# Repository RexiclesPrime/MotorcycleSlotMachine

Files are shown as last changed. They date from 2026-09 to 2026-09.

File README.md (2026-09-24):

# Motorcycle Slot Machine

On power-on, an ESP32 picks today's bike on a three-reel e-ink slot.

The glass on the bench is black, white, and red. That panel lands on the result. A black-and-white panel spins the reels, then settles. The switch is `PANEL_COLORS` in `firmware/motorcycle_slot/config.h`: `3` or `2`.

| Code | Bike |
|---|---|
| **R6** | 2020 Yamaha R6 |
| **R12** | BMW R12 |
| **TT** | Triumph Thruxton R |
| **HS** | Honda Shadow (red bodywork) |
| **JP** | Jackpot — *Buy another motorcycle.* (red bow) |

Bikes are equally likely. Jackpot is about 1% (`2/198`). Reels draw 128×96 side-view sprites. After the result the ESP32 sleeps; tap a button on **GPIO 4** (to GND) to roll again. Wall case: `hardware/enclosure/`. Sources live in `assets/pixel/`; rebuild with `python tools/png_to_bitmap.py`.

## Hardware

- WeAct 4.2" e-paper, 400×300
  - 3-color, black/white/red (GDEY042Z98) — `PANEL_COLORS 3`
  - 2-color, black/white (GDEY042T81) — `PANEL_COLORS 2`
- ESP32 e-Paper Driver Board (USB 5V, 24-pin FPC)

## Load it onto a board

Step-by-step for a first-time Arduino user (plug in the screen, install the IDE, upload): **[HOW-TO-LOAD.md](HOW-TO-LOAD.md)**.

## License

[MIT](LICENSE) for the firmware, the case, and the project docs. Photographs in `assets/pixel/src/` are reference art for the sprites and are not covered by that license.

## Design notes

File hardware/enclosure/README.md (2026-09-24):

# Garage wall enclosure

Two-part PETG case: 4.2" e-paper on the front, ESP32 driver board + 18650 + charger behind, 16 mm **SPIN** button under the screen, keyholes to hang it.

Open `slot_wall_case.scad` in [OpenSCAD](https://openscad.org/). Set `part = "front";` then **F6 → Export STL**. Repeat with `part = "back";`.

Print **PETG** (a summer garage will warp PLA). 0.2 mm layers, 4 perimeters, 25 % infill, no supports if the USB cutouts print with bridging.

Outside is about **100 × 120 × 40 mm**. Measure your glass before the first print; the pocket is 91.5 × 77.5 mm for the usual 91 × 77 × 1.2 mm 4.2" panel.

## Spin button

Use a **16 mm stainless anti-vandal momentary (1NO)** panel switch. Garage dust and gloves, no arcade-button grit trap. Search: `16mm anti-vandal momentary 1NO stainless`. About $6. Panel thickness here is 2.6 mm (the switch’s spec range is usually 1–10 mm).

Skip the LED unless you want it — the ESP32 is asleep most of the time, so a lit button is extra drain.

Wire:

- One switch pin → **GND**
- Other switch pin → **IO4** on the ESP32 driver board (RTC pin, firmware `PIN_SPIN_BUTTON 4`)

Do **not** use BOOT (GPIO0). That is for flashing.

## Battery

Waveshare’s **5V** pin is specified **3.6–5.5 V**, so a single Li-ion cell can feed it directly.

| Part | Why |
|---|-----|
| **Protected 18650** (Panasonic NCR18650B or similar, with the PCB cap) | Garage-safe, ~2500–3400 mAh. Deep sleep + e-ink is months, not hours. |
| **TP4056 Type-C charger with protection** (DW01 / FS8205) | Charge through a hole in the bottom. Do not buy the tiny unprotected-only boards. |

Wiring:

```
USB-C  →  TP4056  B+ / B-  →  18650
                 OUT+  →  ESP32  5V pin
                 OUT-  →  ESP32  GND
```

If your TP4056 has no separate OUT pads, B+ / B- *are* the load — that is still 3.7–4.2 V into the 5V pin, which the board allows.

Leave the ESP32’s own USB for firmware, accessed through the side window or by popping the back.

## Assembly

1. Press four **M3 heat-set inserts** into the back bosses.
2. Stick a 1 mm EVA / craft-foam ring on the back’s glass rib (only the frame, not the picture area).
3. Drop the glass into the front pocket. FPC folds down into the bay — do not crease it sharply.
4. Seat the ESP32 (USB toward the side window), 18650 in the trough, TP4056 USB-C in the bottom cutout. Hot-glue the charger if it rattles.
5. Screw the back on with **M3×12**. Do not pinch the glass; the foam should just kiss the border.
6. Hang on two #8 pan-head screws, 60 mm apart, 14 mm down from the top.

Power on: 3-color glass takes 15–20 s to land on **TODAY'S RIDE**. 2-color glass spins the reels, then shows the same line. Tap **SPIN** to wake and roll again. The glass switch is `PANEL_COLORS` in `firmware/motorcycle_slot/config.h`.

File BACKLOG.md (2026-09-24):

# Punch list

Reviewed `main` at `788aa67` on 2026-09-24: firmware, art tool, odds check, and the wall case. Boot is in good shape. Power-on draws the result with a full refresh, then deep sleep. The old "spins forever" hang is capped.

The BMW R12 reel uses the studio photo from `R12.webp`, mirrored to face right with the other bikes. Reel art is `assets/pixel/src/r9.sprite.png` (128×96). The untouched photo is `assets/pixel/src/r12.webp`. Rebuild with `python tools/png_to_bitmap.py`.

## Decided

- The bench glass is black/white/red. `PANEL_COLORS` is `3`, and that build lands on the result. Set it to `2` for the black-and-white panels. The reels animate only on 2-color glass.
- The button may reroll. "TODAY'S RIDE" is the label, not a once-a-day lock.
- On a 2-color spin, a reel may flash the jackpot. That fake-out stays.
- License is MIT (`LICENSE`). Photographs in `assets/pixel/src/` are not part of that grant.

## P0 — overlapping reels, or a case that will not screw together

1. **Reel frames overlap, and the sprite is wider than its window.** On a 400×300 panel, `layOut()` in `motorcycle_slot.ino` makes each window 125×198 with a 6px gap. The frame is drawn 6px outside the window, so neighboring frames sit on the same pixels. `paintBadge()` then centers the 128px-wide bitmap in that 125px window, so 1–2px of every bike lands on the frame. Widen the gap, or shrink the art to the window.

2. **The wall case has no plastic around the screws.** In `hardware/enclosure/slot_wall_case.scad`, the M3 heat-set holes are 7mm deep, cut through a 2.6mm back wall, with no boss. An insert there has nothing to grip. Add corner bosses at least as deep as the insert before the first print.

## P1 — names, the spin button, and the art tool

3. **R6 and R12 are still called R7 and R9 in the code.** The glass labels are R6 and R12. The enum, the weight macros, the bitmap symbols, and the source files are still `R7` / `R9`. `tools/odds_check.py` prints `R9` for the BMW. One set of names, used everywhere.

4. **Holding the spin button can roll a second time.** Production arms `esp_sleep_enable_ext0_wakeup` on GPIO4, level low, then sleeps. Ext0 wakes if the pin is already low, so a press that outlasts the refresh starts another spin. Test mode already ignores a stuck pin. Production should wait until GPIO4 is high, then sleep. Confirm on the board.

5. **`SPRITE_INVERT` flips only the black plane.** In `paintBadge()`, the red bitmap is always drawn with `drawBitmap`. On a 3-color panel, inverting the bikes leaves the Shadow's paint and the jackpot bow alone.

6. **The art tool flattens a dark bike.** `tools/png_to_bitmap.py` marks any pixel darker than 200 as ink, then nearest-neighbor scales. A black motorcycle becomes a blob, and a gray floor shadow becomes a puddle. That is why the R12 is an authored `r9.sprite.png` instead of a straight threshold of the photo. Downscale first, and drop the near-white background, before the next photo.

## P2 — housekeeping

7. **The test splash still says "sprites on".** `bootSplash()` is leftover debug copy. Production never shows it. A real title, or no splash.

8. **The odds table is copied in two places.** Weights live in `config.h` and again in `odds_check.py`, which is how the checker ended up saying R9. One table.

9. **GPIO12 is claimed as MISO.** The e-paper board does not need a MISO line, and GPIO12 is an ESP32 strapping pin (flash voltage). Not claiming it avoids a boot failure if the ribbon floats that pin.

10. **Charger wiring in the enclosure notes.** `hardware/enclosure/README.md` says a TP4056 with no OUT pads can feed the ESP32 from B+ / B-. That is fine until the board is charging and running at the same time. Call for a load-sharing charger if this lives on USB-C in the garage.

11. **No check that the art and the odds still match.** A small script run (odds check, plus a diff of `bitmaps.h` after `png_to_bitmap.py`) would catch the next drift. Nothing in the repo runs either today.

## Leave alone

- `esp_random() % 198` is a hair off a perfect 2/198 jackpot. Nobody will see it.
- The 4-page cap in the draw loops. With a full-height buffer the draw is one page. That cap is what stopped the boot hang.

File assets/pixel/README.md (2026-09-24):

# Pixel art

Side-view 1-bit sprites for the three reels.

| File | Bike |
|---|---|
| `src/r7.jpg` | 2020 Yamaha R6 |
| `src/r9.jpg` | BMW R12 photo, mirrored so it faces right like the other reels |
| `src/r9.sprite.png` | BMW R12 reel art, already 128×96. The tool uses this as-is |
| `src/r12.webp` | BMW R12 studio photo, original (faces left) |
| `src/tt.jpg` | Triumph Thruxton R (cafe fairing) |
| `src/hs.jpg` | Honda Shadow (red body) |
| `src/jp.jpg` | Jackpot (gift-wrapped extra bike) |

Filenames `r7` and `r9` are older names. On the glass those reels are **R6** and **R12**.

`python tools/png_to_bitmap.py` writes 128×96 `1bit/*.png` and `firmware/motorcycle_slot/bitmaps.h`. A `src/<name>.sprite.png` at exactly 128×96 is copied through. Anything else is thresholded from the photo.

The MIT license does not cover these photographs. They are references for the reel sprites.

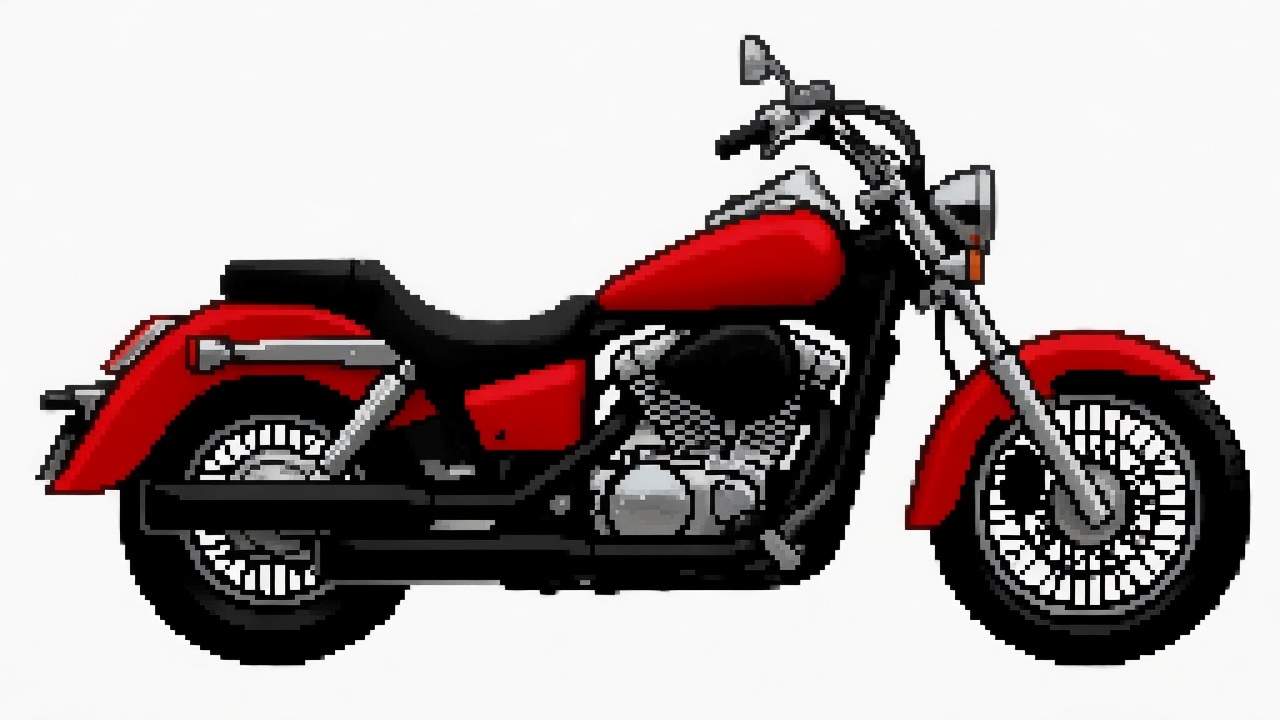
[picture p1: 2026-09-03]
assets/pixel/src/hs.jpg

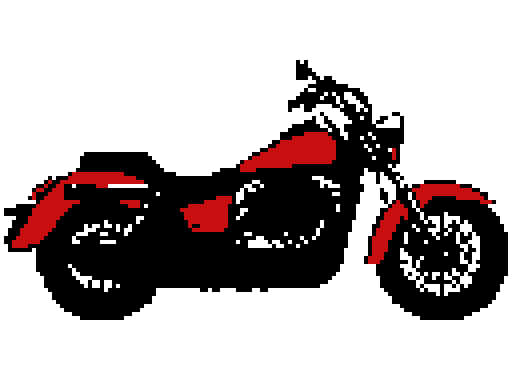
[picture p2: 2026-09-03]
assets/pixel/1bit/hs_x4.png

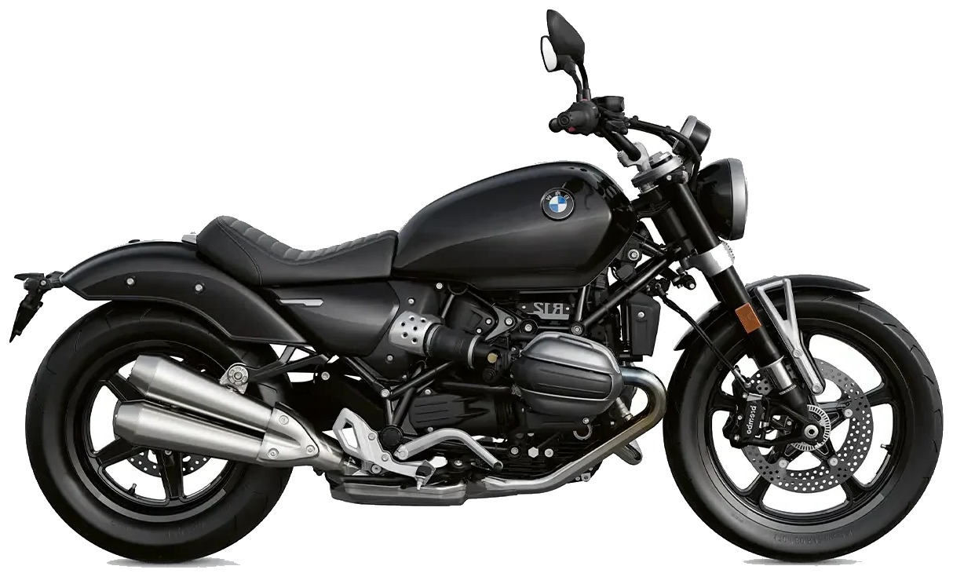
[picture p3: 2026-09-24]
assets/pixel/src/r9.jpg

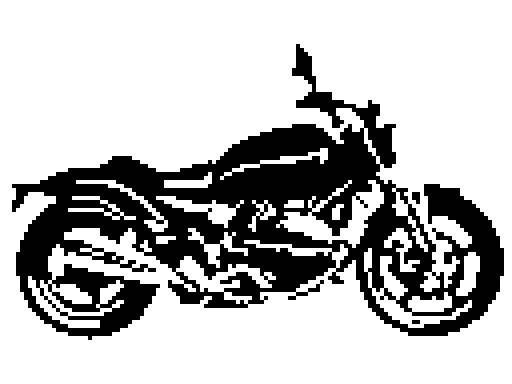
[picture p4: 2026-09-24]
assets/pixel/1bit/r9_x4.png

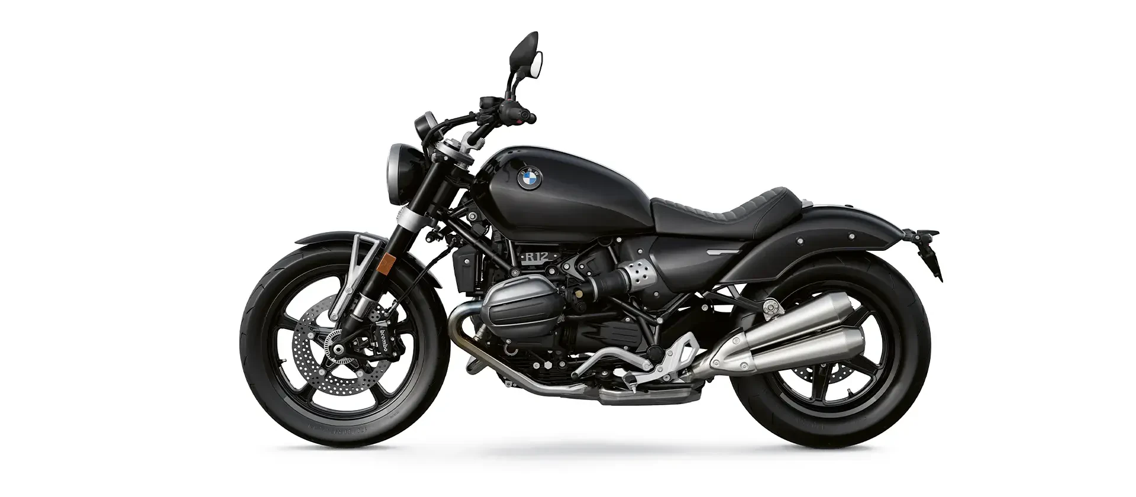
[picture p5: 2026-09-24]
assets/pixel/src/r12.webp

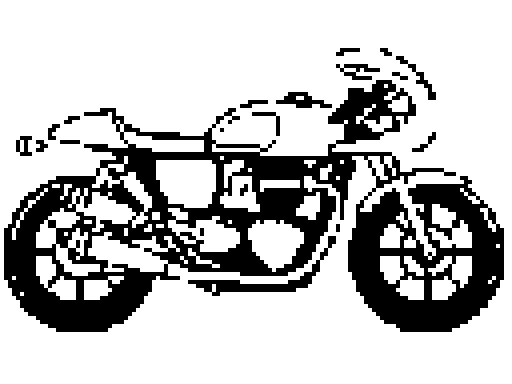
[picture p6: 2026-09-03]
assets/pixel/1bit/tt_x4.png

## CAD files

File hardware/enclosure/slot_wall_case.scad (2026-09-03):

// Motorcycle Slot Machine — garage wall case
// Units: millimetres
// OpenSCAD: set part = "front" or "back", press F6, File → Export → STL
// Print PETG (garage heat), 0.2 mm layers, 4 perimeters, 25% infill.

part = "preview"; // "front", "back", "preview"

$fn = 48;
clear = 0.35;

// --- 4.2" glass (WeAct / Good Display 400x300) ---
glass_w = 91.0;
glass_h = 77.0;
glass_t = 1.4;
aa_w = 84.8;
aa_h = 63.6;

// --- Waveshare ESP32 e-Paper Driver Board ---
esp_l = 48.5;
esp_w = 29.8;
esp_t = 8.5;

// --- 18650 + typical dual-slot holder / single keystone ---
cell_d = 19.2;
cell_l = 69.0;

// --- TP4056 Type-C charger (with protection) ---
chg_l = 27.0;
chg_w = 18.0;
chg_t = 6.0;

// --- 16 mm anti-vandal momentary ---
btn_hole = 16.2;
btn_boss_t = 2.6; // panel thickness at the button

wall = 2.6;
lip = 1.6;          // front window lip over the glass
bezel = 3.2;        // glass overlap around the active area
gap_g = 0.5;        // glass pocket clearance

inner_w = glass_w + 2 * gap_g;
inner_h = glass_h + 2 * gap_g;
win_w = aa_w - 1.2;
win_h = aa_h - 1.2;

btn_zone = 28;
case_w = inner_w + 2 * wall + 4;
case_h = inner_h + btn_zone + 2 * wall + 6;
case_d = wall + glass_t + 2.0 + esp_t + cell_d + wall; // ~40

front_t = wall + lip + glass_t + 1.2;
back_t = case_d - front_t + 1.2; // overlap seam

screw_r = 1.6;      // M3 clearance
insert_r = 2.05;    // M3 heat-set insert
boss_r = 4.2;

module rrect(s, r) {
  hull() {
    for (x = [r, s[0] - r], y = [r, s[1] - r])
      translate([x, y]) circle(r = r);
  }
}

module rbox(s, r) {
  linear_extrude(s[2]) rrect([s[0], s[1]], r);
}

module screw_xy() {
  m = wall + 3.5;
  for (x = [m, case_w - m], y = [m, case_h - m])
    translate([x, y]) children();
}

module keyhole() {
  // #8 / 4 mm screw, hang and drop
  hull() {
    circle(d = 8.5);
    translate([0, -7]) circle(d = 4.4);
  }
}

module front() {
  gx = (case_w - inner_w) / 2;
  gy = case_h - wall - 4 - inner_h;
  wx = gx + (inner_w - win_w) / 2;
  wy = gy + (inner_h - win_h) / 2;

  difference() {
    union() {
      rbox([case_w, case_h, front_t], 4);
      translate([wall - 0.8, wall - 0.8, front_t])
        rbox([case_w - 2 * wall + 1.6, case_h - 2 * wall + 1.6, 1.4], 3);
    }

    translate([wx, wy, -0.1])
      cube([win_w, win_h, front_t + 3]);

    translate([gx, gy, lip])
      cube([inner_w, inner_h, front_t]);

    // FPC folds down from the bottom edge of the glass
    translate([case_w / 2 - 9, gy - 3, lip + 0.3])
      cube([18, 6, front_t]);

    translate([case_w / 2, wall + 7 + btn_hole / 2, -0.1])
      cylinder(d = btn_hole, h = front_t + 4);

    screw_xy()
      translate([0, 0, -0.1]) cylinder(r = screw_r, h = front_t + 4);
  }

  translate([case_w / 2, wall + 7 + btn_hole + 5.2, front_t - 0.45])
    linear_extrude(0.55)
      text("SPIN", size = 4, halign = "center", valign = "center");
}

module back() {
  difference() {
    rbox([case_w, case_h, back_t], 4);

    // main cavity
    translate([wall, wall, wall])
      rbox([case_w - 2 * wall, case_h - 2 * wall, back_t], 3);

    // seam rebate for the front lip
    translate([wall - 1.0, wall - 1.0, back_t - 1.6])
      rbox([case_w - 2 * wall + 2.0, case_h - 2 * wall + 2.0, 2.2], 3);

    // M3 heat-set inserts
    screw_xy()
      translate([0, 0, -0.1]) cylinder(r = insert_r, h = 7);

    // USB-C charge (TP4056) on the bottom
    translate([case_w / 2 - 5, -0.1, wall + 4])
      cube([10, wall + 2, 6]);

    // ESP32 USB (programming) on the right side, case open not required if you
    // leave a 12 x 8 window — still easier to pop the back. Side window:
    translate([case_w - wall - 0.1, wall + 10, wall + 3])
      cube([wall + 1, 12, 8]);

    // keyholes (hang on two #8 pan heads)
    translate([case_w / 2 - 30, case_h - 14, -0.1])
      linear_extrude(wall + 0.3) keyhole();
    translate([case_w / 2 + 30, case_h - 14, -0.1])
      linear_extrude(wall + 0.3) keyhole();
  }

  // ESP32 standoffs (board sits USB toward the side window)
  translate([wall + 8, wall + 8, wall])
    for (x = [3, esp_l - 3], y = [3, esp_w - 3])
      translate([x, y, 0]) {
        difference() {
          cylinder(r = 3.2, h = 4);
          translate([0, 0, 1.2]) cylinder(r = 0.9, h = 4); // M2 self-tap
        }
      }

  // 18650 trough
  translate([wall + 8, wall + 8 + esp_w + 8, wall])
    difference() {
      cube([cell_l + 4, cell_d + 4, cell_d * 0.55]);
      translate([2, 2, 2]) cube([cell_l, cell_d, cell_d]);
    }

  // foam rib that presses the glass perimeter (not the active area)
  translate([(case_w - (inner_w - 6)) / 2,
             case_h - wall - 3 - inner_h + 3,
             back_t - 3.2])
    difference() {
      cube([inner_w - 6, inner_h - 6, 1.8]);
      translate([4, 4, -0.1])
        cube([inner_w - 14, inner_h - 14, 3]);
    }
}

if (part == "front") front();
else if (part == "back") back();
else {
  front();
  translate([case_w + 12, 0, 0]) back();
}

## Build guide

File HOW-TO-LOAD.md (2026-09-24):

# How to load this onto the hardware

You need:

- A **WeAct 4.2" e-paper** module (the glass + short ribbon cable)
- An **ESP32 e-Paper Driver Board** (the small USB board with a ribbon-cable socket)
- A USB cable that actually carries data (not charge-only)
- A computer with [Arduino IDE](https://www.arduino.cc/en/software) (version 2 is fine)

No extra jumper wires. The screen plugs into the driver board; the driver board plugs into the computer.

## 1. Connect the screen to the driver board

E-paper glass is fragile. Hold it by the edges. Do not press the face.

1. On the driver board, find the **24-pin FPC socket** (the thin slot with a plastic latch).
2. Gently lift the latch.
3. Slide the screen’s ribbon in **straight and fully**. Gold contacts go toward the contacts in the socket. If it fights you, you have it upside down — flip the ribbon, don’t force it.
4. Press the latch back down so the cable is locked.
5. Set the small **display / resistor switch** to **A** (often labeled **3R**). Leave the SPI switch on **4-line** if the board has one.

Then plug the driver board into the computer with USB. A power LED should light. If Windows pops up “USB device,” that is normal.

## 2. Install Arduino IDE and the ESP32 board package

1. Install Arduino IDE and open it.
2. **File → Preferences**. In *Additional boards manager URLs* paste:

   `https://espressif.github.io/arduino-esp32/package_esp32_index.json`

   Click OK.
3. **Tools → Board → Boards Manager…**
4. Search **esp32**. Install **esp32** by **Espressif Systems**. Close the manager.

## 3. Install the three libraries

This step is required. Installing only GxEPD2 is not enough — the fonts live in Adafruit GFX.

**Sketch → Include Library → Manage Libraries…** Search each name below, click **Install**, and accept **Install all** if it asks for dependencies.

| Search for | Author to pick |
|---|---|
| `GxEPD2` | Jean-Marc Zingg |
| `Adafruit GFX Library` | Adafruit |
| `Adafruit BusIO` | Adafruit |

To confirm GFX is actually there: **Sketch → Include Library** should list **Adafruit GFX Library**. If it does not, install it again (close and reopen the Library Manager if the list looks stale).

## 4. Open this project and pick the board

1. Get a **fresh** copy: GitHub **Code → Download ZIP**, unzip it, and throw away any older `MotorcycleSlotMachine-main` folder. Do not copy one new file into an old sketch folder — `bitmaps.h` has to sit next to the `.ino`.
2. In Arduino IDE: **File → Open…** and choose

   `firmware/motorcycle_slot/motorcycle_slot.ino`

   That folder must contain `motorcycle_slot.ino`, `config.h`, and `bitmaps.h`.
3. **Tools → Board → esp32 → ESP32 Dev Module**
4. **Tools → Port** → the new COM port that appeared when you plugged the board in.

If there is no port: try another USB cable, another USB jack, or install a **CP2102** (or **CH340**) USB driver, then unplug and replug.

## 5. Upload

Click **Upload** (the right arrow). Wait until the bottom log says **Done uploading**.

If it sits on “Connecting…” or fails to sync:

1. Hold **BOOT** on the driver board.
2. Tap **EN** / **RESET** once.
3. Release **BOOT**.
4. Click Upload again.

## 6. What you should see

Production boot depends on `PANEL_COLORS` in `firmware/motorcycle_slot/config.h`. The picture stays with the power off either way.

- **`3`** (black/white/red, the default): the board lands on **TODAY'S RIDE** (or **JACKPOT**), then sleeps. The reels do not animate. A refresh takes 15–20 seconds — wait for the footer, not a splash screen.
- **`2`** (black/white): the reels spin once, draw the same footer, then sleep.

Optional **spin button**: 16 mm momentary switch from **GPIO 4 (IO4)** to **GND**. Tap it to wake and roll again. **BOOT is only for flashing**, not for spinning. See `hardware/enclosure/` for the wall case.

If you fit a 2-color panel and the screen goes blank or crazy, set `#define PANEL_COLORS 2` in `config.h` and upload again. If the bikes look inverted, set `#define SPRITE_INVERT 1`.

Serial **115200**: `land ->` then `done`. To stay awake and force bikes, set `TEST_MODE` to `1` (`s` / `1`–`4` / `j`).

## If compile fails

**`Fonts/FreeSansBold9pt7b.h: No such file or directory`**

Adafruit GFX is missing. Repeat section 3 and install **Adafruit GFX Library** by Adafruit (and **Adafruit BusIO** if prompted). Then **Sketch → Verify/Compile** again. Restart Arduino IDE if it still cannot see the library.

**`GxEPD2_BW.h: No such file or directory`**

Install **GxEPD2** by Jean-Marc Zingg.

## If the screen stays blank

Work down this list. Change **one** thing at a time, then upload again.

1. Ribbon fully seated, latch closed, switch on **A**.
2. `PANEL_COLORS` matches the glass: `3` for black/white/red, `2` for black/white.
3. On a 2-color panel that is still blank, set `#define WEACT_PANEL_ALT 1`.
4. Still blank: try the display switch on **B**.
5. Picture is there but sideways: set `#define DISPLAY_ROTATION 1` (then `3` if needed).
6. Picture is inverted or garbage: `WEACT_PANEL_ALT` the other way (`0` or `1`).

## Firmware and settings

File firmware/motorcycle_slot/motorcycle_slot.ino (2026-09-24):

// Motorcycle Slot Machine
// WeAct 4.2" e-paper (400x300, SSD1683) + ESP32 e-Paper Driver Board.
// On power-up, pick today's bike (or a jackpot).
// PANEL_COLORS 3 lands on the result. PANEL_COLORS 2 spins, then settles.

#include <Arduino.h>
#include <SPI.h>
#include <esp_sleep.h>
#include <driver/rtc_io.h>
#include <Adafruit_GFX.h>
#include <Fonts/FreeSansBold9pt7b.h>
#include <Fonts/FreeSansBold12pt7b.h>

#define ENABLE_GxEPD2_GFX 0
#include "config.h"
#if PANEL_COLORS == 3
#include <GxEPD2_3C.h>
#else
#include <GxEPD2_BW.h>
#endif
#include "bitmaps.h"

// Driver board FPC: CS 15, DC 27, RST 26, BUSY 25, SCK 13, MOSI 14 (HSPI, SCK/MOSI swapped vs default).
static const int PIN_CS = 15;
static const int PIN_DC = 27;
static const int PIN_RST = 26;
static const int PIN_BUSY = 25;
static const int PIN_SCK = 13;
static const int PIN_MISO = 12;
static const int PIN_MOSI = 14;

#if PANEL_COLORS == 3
using Panel = GxEPD2_420c_GDEY042Z98;
static GxEPD2_3C<Panel, Panel::HEIGHT> epd(Panel(PIN_CS, PIN_DC, PIN_RST, PIN_BUSY));
#elif WEACT_PANEL_ALT
using Panel = GxEPD2_420_GYE042A87;
static GxEPD2_BW<Panel, Panel::HEIGHT> epd(Panel(PIN_CS, PIN_DC, PIN_RST, PIN_BUSY));
#else
using Panel = GxEPD2_420_GDEY042T81;
static GxEPD2_BW<Panel, Panel::HEIGHT> epd(Panel(PIN_CS, PIN_DC, PIN_RST, PIN_BUSY));
#endif
static SPIClass epdBus(HSPI);

enum Badge : uint8_t { R7 = 0, R9, TT, HS, JP, BADGE_N };

static const char* kCode[BADGE_N] = {"R6", "R12", "TT", "HS", "JP"};
static const char* kName[BADGE_N] = {
    "2020 Yamaha R6", "BMW R12", "Triumph Thruxton R", "Honda Shadow", "JACKPOT"};
static const uint16_t kWeight[BADGE_N] = {W_R7, W_R9, W_TT, W_HS, W_JP};
static const unsigned char* kBmp[BADGE_N] = {bmp_r7, bmp_r9, bmp_tt, bmp_hs, bmp_jp};
static const unsigned char* kBmpRed[BADGE_N] = {bmp_r7_red, bmp_r9_red, bmp_tt_red, bmp_hs_red, bmp_jp_red};

struct Window {
  int16_t x, y, w, h;
};

static Window gReel[3];
static int16_t gW, gH;

static uint16_t weightSum() {
  uint16_t s = 0;
  for (uint8_t i = 0; i < BADGE_N; i++) s = (uint16_t)(s + kWeight[i]);
  return s;
}

static Badge pickBadge(uint32_t rng) {
  uint16_t n = (uint16_t)(rng % weightSum());
  for (uint8_t i = 0; i < BADGE_N; i++) {
    if (n < kWeight[i]) return (Badge)i;
    n = (uint16_t)(n - kWeight[i]);
  }
  return R7;
}

// Jackpot is included on purpose. On a 2-color panel, a black card
// during the whirl is a fake-out before the real result lands.
static Badge scramble() {
  return (Badge)(esp_random() % BADGE_N);
}

static void centerText(const char* s, int16_t cx, int16_t cy, const GFXfont* font, uint16_t color) {
  epd.setFont(font);
  epd.setTextColor(color);
  int16_t x, y;
  uint16_t w, h;
  epd.getTextBounds(s, 0, 0, &x, &y, &w, &h);
  epd.setCursor((int16_t)(cx - (int16_t)w / 2 - x), (int16_t)(cy - (int16_t)h / 2 - y));
  epd.print(s);
}

static void paintBadge(const Window& win, Badge b) {
  const bool jack = (b == JP);
  const uint16_t bg = jack ? GxEPD_BLACK : GxEPD_WHITE;
  const uint16_t fg = jack ? GxEPD_WHITE : GxEPD_BLACK;
  epd.fillRect(win.x, win.y, win.w, win.h, bg);
#if USE_SPRITES
  const int16_t bx = (int16_t)(win.x + (win.w - (int16_t)bmp_r7_w) / 2);
  const int16_t by = (int16_t)(win.y + (win.h - (int16_t)bmp_r7_h) / 2);
#if SPRITE_INVERT
  epd.drawInvertedBitmap(bx, by, kBmp[b], bmp_r7_w, bmp_r7_h, fg);
#else
  epd.drawBitmap(bx, by, kBmp[b], bmp_r7_w, bmp_r7_h, fg);
#endif
#if PANEL_COLORS == 3
  const uint16_t red = GxEPD_RED;
#else
  const uint16_t red = jack ? GxEPD_WHITE : GxEPD_BLACK;
#endif
  epd.drawBitmap(bx, by, kBmpRed[b], bmp_r7_w, bmp_r7_h, red);
#else
  centerText(kCode[b], (int16_t)(win.x + win.w / 2), (int16_t)(win.y + win.h / 2),
             &FreeSansBold12pt7b, fg);
#endif
}

static void paintChrome(const Badge shown[3], const char* line1, const char* line2) {
  epd.fillScreen(GxEPD_WHITE);

  epd.fillRect(0, 0, gW, 36, GxEPD_BLACK);
  centerText("WHICH RIDE?", (int16_t)(gW / 2), 18, &FreeSansBold12pt7b, GxEPD_WHITE);

  for (int i = 0; i < 3; i++) {
    const Window& f = gReel[i];
    epd.drawRoundRect(f.x - 6, f.y - 6, f.w + 12, f.h + 12, 8, GxEPD_BLACK);
    epd.drawRoundRect(f.x - 4, f.y - 4, f.w + 8, f.h + 8, 6, GxEPD_BLACK);
    paintBadge(f, shown[i]);
  }

  if (line1 && line1[0]) {
    centerText(line1, (int16_t)(gW / 2), (int16_t)(gH - 32), &FreeSansBold12pt7b, GxEPD_BLACK);
  }
  if (line2 && line2[0]) {
    centerText(line2, (int16_t)(gW / 2), (int16_t)(gH - 12), &FreeSansBold9pt7b, GxEPD_BLACK);
  }
}

static void fullFrame(const Badge shown[3], const char* line1, const char* line2) {
  epd.setFullWindow();
  epd.firstPage();
  int pages = 0;
  do {
    paintChrome(shown, line1, line2);
  } while (epd.nextPage() && ++pages < 4);
}

static void flipReels(const Badge shown[3]) {
  const int16_t x = gReel[0].x;
  const int16_t y = gReel[0].y;
  const int16_t w = (int16_t)(gReel[2].x + gReel[2].w - gReel[0].x);
  const int16_t h = gReel[0].h;
  epd.setPartialWindow(x, y, w, h);
  epd.firstPage();
  int pages = 0;
  do {
    epd.fillScreen(GxEPD_WHITE);
    for (int i = 0; i < 3; i++) paintBadge(gReel[i], shown[i]);
  } while (epd.nextPage() && ++pages < 4);
  delay(1);
}

static void layOut() {
  gW = epd.width();
  gH = epd.height();

  const int16_t gap = 6;
  const int16_t side = 6;
  const int16_t top = 44;
  const int16_t bottom = 58;
  const int16_t rw = (int16_t)((gW - 2 * side - 2 * gap) / 3);
  const int16_t rh = (int16_t)(gH - top - bottom);

  for (int i = 0; i < 3; i++) {
    gReel[i].x = (int16_t)(side + i * (rw + gap));
    gReel[i].y = top;
    gReel[i].w = rw;
    gReel[i].h = rh;
  }
}

static void bootSplash() {
  epd.setFullWindow();
  epd.firstPage();
  int pages = 0;
  do {
    epd.fillScreen(GxEPD_WHITE);
    centerText("SLOT", (int16_t)(gW / 2), (int16_t)(gH / 2 - 14), &FreeSansBold12pt7b, GxEPD_BLACK);
    centerText("sprites on", (int16_t)(gW / 2), (int16_t)(gH / 2 + 14), &FreeSansBold9pt7b, GxEPD_BLACK);
  } while (epd.nextPage() && ++pages < 4);
}

static void spinTo(Badge landOn) {
  Badge face[3] = {scramble(), scramble(), scramble()};

  Serial.printf("land -> %s  %s\n", kCode[landOn], kName[landOn]);

  int whirl = SPIN_WHIRL;
  int settle = SPIN_SETTLE;
#if PANEL_COLORS == 3
  // Black/white/red glass cannot partial-refresh. Land on the result.
  whirl = 0;
  settle = 0;
#else
  if (!epd.epd2.hasPartialUpdate) {
    whirl = 0;
    settle = 0;
  }
#endif
  if (whirl > 0 || settle > 0) {
    fullFrame(face, "SPINNING", "");
  }

  for (int n = 0; n < whirl; n++) {
    face[0] = scramble();
    face[1] = scramble();
    face[2] = scramble();
    Serial.printf("whirl %d\n", n);
    flipReels(face);
  }
  face[0] = landOn;
  for (int n = 0; n < settle; n++) {
    face[1] = scramble();
    face[2] = scramble();
    flipReels(face);
  }
  face[1] = landOn;
  for (int n = 0; n < settle; n++) {
    face[2] = scramble();
    flipReels(face);
  }
  face[0] = face[1] = face[2] = landOn;

  if (landOn == JP) {
    fullFrame(face, "JACKPOT", "Buy another motorcycle.");
  } else {
    fullFrame(face, "TODAY'S RIDE", kName[landOn]);
  }
  Serial.println("done — reels should be stopped");
}

static void spinRandom() { spinTo(pickBadge(esp_random())); }

static bool bootHeld() {
#if PIN_SPIN_BUTTON < 0
  return false;
#else
  return digitalRead(PIN_SPIN_BUTTON) == LOW;
#endif
}

static void eatSerial() {
#if SERIAL_COMMANDS
  if (Serial.available() <= 0) return;
  const int c = Serial.read();
  if (c == 's' || c == 'S') spinRandom();
  else if (c == '1') spinTo(R7);
  else if (c == '2') spinTo(R9);
  else if (c == '3') spinTo(TT);
  else if (c == '4') spinTo(HS);
  else if (c == 'j' || c == 'J') spinTo(JP);
#endif
}

static void nap() {
  Serial.println("sleep — tap the GPIO4 button to spin again");
  epd.hibernate();
#if PIN_SPIN_BUTTON >= 0
  rtc_gpio_init((gpio_num_t)PIN_SPIN_BUTTON);
  rtc_gpio_set_direction((gpio_num_t)PIN_SPIN_BUTTON, RTC_GPIO_MODE_INPUT_ONLY);
  rtc_gpio_pullup_en((gpio_num_t)PIN_SPIN_BUTTON);
  rtc_gpio_pulldown_dis((gpio_num_t)PIN_SPIN_BUTTON);
  esp_sleep_enable_ext0_wakeup((gpio_num_t)PIN_SPIN_BUTTON, 0);
#endif
  esp_deep_sleep_start();
}

void setup() {
  Serial.begin(115200);
  delay(80);
  Serial.println("Motorcycle Slot Machine");
  Serial.printf("JP chance %u/%u\n", W_JP, weightSum());
#if TEST_MODE
  Serial.println("TEST_MODE: s=spin  1=R6 2=R12 3=TT 4=HS  j=jackpot");
#else
  Serial.println("production: one spin, then sleep");
#endif
#if PANEL_COLORS == 3
  Serial.println("3-color: landing on the result, full refresh 15-20s");
#else
  Serial.println("2-color: reels will spin");
#endif

#if PIN_SPIN_BUTTON >= 0
  pinMode(PIN_SPIN_BUTTON, INPUT_PULLUP);
#endif

  Serial.println("init display...");
  epdBus.begin(PIN_SCK, PIN_MISO, PIN_MOSI, PIN_CS);
  epd.epd2.selectSPI(epdBus, SPISettings(4000000, MSBFIRST, SPI_MODE0));
  epd.init(115200, true, 50, false);
  epd.setRotation(DISPLAY_ROTATION);
  epd.setTextWrap(false);
  layOut();
  Serial.printf("panel %dx%d  partial=%d fast=%d  sprites=%d  colors=%d\n", gW, gH,
                epd.epd2.hasPartialUpdate, epd.epd2.hasFastPartialUpdate, USE_SPRITES, PANEL_COLORS);

#if TEST_MODE
  bootSplash();
#endif
  spinRandom();
#if !TEST_MODE
  nap();
#endif
}

void loop() {
#if TEST_MODE
  eatSerial();

  // Falling edge only so a stuck pin cannot respin forever.
  static bool bootWasHeld = true;
  const bool held = bootHeld();
  if (held && !bootWasHeld) {
    uint32_t t = millis();
    while (bootHeld() && millis() - t < 1500) delay(10);
    spinRandom();
  }
  bootWasHeld = held;
  delay(20);
#else
  delay(1000);
#endif
}

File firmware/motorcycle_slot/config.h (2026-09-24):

#pragma once

// WeAct 4.2" (400x300) on an ESP32 e-Paper Driver Board.
//
// Glass switch:
//   3 = black / white / red (GDEY042Z98). The panel on the bench.
//       Lands on the result. This glass cannot partial-refresh, so the
//       reels do not animate.
//   2 = black / white (GDEY042T81). The next batch of panels.
//       Reels spin, then settle.
#define PANEL_COLORS 3
#if (PANEL_COLORS != 2) && (PANEL_COLORS != 3)
#error PANEL_COLORS must be 2 or 3
#endif
// Only used when PANEL_COLORS is 2. Set to 1 (GYE042A87) if that
// black-and-white picture is blank or inverted.
#define WEACT_PANEL_ALT 0

// Native 4.2" is already landscape. Change only if the slot is sideways (1 or 3).
#define DISPLAY_ROTATION 0

// 0 = production: one spin, then deep sleep (image stays on the glass).
// 1 = stay awake; serial commands respin (for bench testing).
#define TEST_MODE 0

// Dedicated spin/wake button to GND. Do not use GPIO0 (BOOT).
// Waveshare ESP32 driver board: IO4 is on the header and is RTC-capable.
#define PIN_SPIN_BUTTON 4

// E-ink frames. Each partial refresh is ~0.5–2s on the 4.2". Keep this tiny.
#define SPIN_WHIRL 1
#define SPIN_SETTLE 1

// Serial 115200: s = spin, 1-4 = R6/R12/TT/HS, j = jackpot
#define SERIAL_COMMANDS 1

// 1 = draw the 128x96 side-view sprites in bitmaps.h. 0 = letter codes only.
#define USE_SPRITES 1
// 1 = swap black/white in the sprite (try this if the bikes look like empty outlines or inverted blobs).
#define SPRITE_INVERT 0

// Four bikes equal. Jackpot is rare. 2/198 ≈ 1.01%.
#define W_R7 49
#define W_R9 49
#define W_TT 49
#define W_HS 49
#define W_JP 2

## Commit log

2026-09-03 Add ESP32 e-ink motorcycle slot machine firmware.
    Power-on spin for WeAct 4.2 inch panel and ESP32 e-Paper Driver Board, with letter-code reels (R7/R9/TT/HS) and a rare jackpot.
2026-09-03 Add a novice how-to-load guide for the e-paper driver board.
    Walks through connecting the WeAct panel, installing Arduino/ESP32, uploading, and a short blank-screen checklist.
2026-09-03 Fix GFX font include and add 1-bit bike sprites.
    Include Adafruit_GFX.h before Fonts/ so Arduino Library Manager actually puts GFX on the include path. Document that compile error. Reels now draw side-view sprites from bitmaps.h.
    [motorcycle_slot.ino]
2026-09-03 Stop the 4.2 inch spin from running forever.
    Cut e-ink frames, disable the ESP32 watchdog during refreshes, and only respin on a BOOT falling edge so a stuck GPIO0 cannot loop.
    [config.h, motorcycle_slot.ino]
2026-09-03 Ship side-view bike sprites on the reels for the next smoke test.
    Keep bitmaps.h next to the sketch, add USE_SPRITES/SPRITE_INVERT switches, and tell loaders to unzip a fresh copy instead of patching an old folder.
2026-09-03 Fix boot hang that left the e-ink image unchanged.
    Remove disableCore0WDT (it can abort before the panel inits) and draw a SLOT splash so a new flash is obvious.
    [motorcycle_slot.ino]
2026-09-03 Production boot: one spin, sleep, larger 128x96 reel sprites.
    Drop the splash and reel letter codes. Wake from a GPIO32 button to GND, not BOOT. 3-color skips the extra SPINNING refresh.
    [config.h, motorcycle_slot.ino]
2026-09-03 Add a PETG wall enclosure, 16mm spin button BOM, and GPIO4 wiring.
    Two-part OpenSCAD case holds the 4.2 inch panel, ESP32 driver, 18650 plus TP4056, and an anti-vandal button. Hang on two keyhole slots.
    [slot_wall_case.scad]
2026-09-04 Give TODAY'S RIDE a few pixels of clearance under the reel frames.
    [motorcycle_slot.ino]
2026-09-24 Draw the black R12 and switch the glass between 2 and 3 colors.
    PANEL_COLORS 3 is the bench panel and lands on the result. Set it to 2
    when the black-and-white glass arrives so the reels spin. The R12 sprite
    faces right with the other bikes. MIT covers the firmware, case, and docs.
2026-09-24 Open the R12 tank and seat so the reel is not one black shape.
    The wheels and the stacked exhaust stay. The body panels are outline
    now, so the tank, seat, and tail read separately on the 3-color glass.
